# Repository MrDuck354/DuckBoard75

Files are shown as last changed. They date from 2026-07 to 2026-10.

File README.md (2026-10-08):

# DuckBoard 75

## Project Goals:
To create a basic 75% keyboard
By creating this keyboard, I will be learning how to 3D model/print on OnShape, how to create a PCB on KiCad and how to solder.

## Project Information
This project was inspired by a recent rabbit hole I went down in on youtube about custom keyboards, creators such as Glarses inspired me to get more into keyboards. Disappointed by my current HP office keyboard I wanted to get a mechanical keyboard but they're surprisingly expensive. I decided to design and build my own custom keyboard which would be a lot more affordable and a great learning opportunity for me. Also I just thought making my own keyboard would be a cool thing to flex on my friends...

The PCB was designed with the help of tutorials made by Joe Scotto on youtube, it doesn't feature anything cool, it's just a simple 75% keyboard PCB.
The case and top plate was made without any tutorials besides one to help me understand how OnShape works as I haven't used any of these softwares before. I want to make the case yellow or orange like a ducks bill so its more on theme for my name. 

My keyboard features 82 standard mechanical keys, its wired with an unpluggable wire but I could make it a permanent wire later on, I used a rp2042 because it seemed to be an option other people were suggesting on reddit, I chose Outemu switches because it was the cheapest option which was also reputable online and I decided on brown tactiles because they sound nice and tactile switches are probably closest to my current membrane keyboard but I don't know because I've never used a mechanical keyboard. I also thought about putting foam in between the bottom and the PCB which I may decided upon later once this project is approved and I get the parts (insert my decision here). There wasn't much thought behind my software choices, I chose OnShape because people online said it was good and I get it for free through my school and I chose KiCad because everyone said it was the best.

## Steps
Made a PCB on KiCad with an arduino nano RP2042 and switches, made the PCB first so that I can model the case around it. 


Made a top plate on OnShape using the PCB as a reference



Made a bottom case to fit everything and put it all together



Created the firmware using iNimbleSloth's tutorial on youtube https://www.youtube.com/watch?v=9bjp_LteX_Y
[Completed](duckboard_firmware)

Soldered the electronics together
(Not yet completed)

For more information on how I made these parts or how they fit together, check my [JOURNAL.md](JOURNAL.md) where I documented my design process.

## OnShape link
Click on the link below then copy and paste the link in a browser to go to OnShape

[OnShape Link](OnShapeLink.md)

Download the files in the link below if you want to edit or view them in another software
The assembly is too big to upload to GitHub so I had to compress it and can only add the .stl file and not the .step file. Unzip the .zip file and download the .stl file to view the case assembly.

[Case Files](DuckBoard_75_Case)

## Bill of Materials
[BOM.csv](DuckBoard%2075%20BOM%20-%20DuckBoard%2075%20BOM%20-%20Sheet1.csv)
| Item | Price (USD) | QTY | Purpose | Total + Shipping |
| --- | --- | --- | --- | --- |
| [PCB](https://cart.jlcpcb.com/quote?spm=jlcpcb.Public.2006) | $27.40 | 5 (minimum) | Electronics for keyboard |  |
| [Juidinto Hex Socket M2 Screws](https://www.aliexpress.com/item/1005004527586307.html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) | $2.33 | 1 | To hold everything together |  |
| [PBT Pudding Keycaps](https://www.aliexpress.com/item/1005012018517535.html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) | $20.65 | 1 | Keycaps |  |
| [DUROCK Plate Mount Stabilizers](https://www.aliexpress.com/item/1005006528731543.html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) | $8.84 | 1 | Stabilizers |  |
| [1N4148 Diodes](https://www.aliexpress.com/item/1005002339916163.html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) | $0.87 | 1 | to control flow of electricity |  |
| [Outemu Tactile Brown Switches](https://www.aliexpress.com/item/1005004285423123.html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) | $3.53 | 90pcs | switches |  |
| [RP2040 PICO Raspberry Pi Microcontroller](https://www.aliexpress.com/item/1005010706615847.html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) | $2.64 | 1 | to control everything |  |
| [Solder Wire](https://www.aliexpress.com/item/1005008618276811.html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) | $1.32 | 1 | to connect electronics |  |
| [3D printing costs](https://www.wcl.govt.nz/services/technology/makerspace/#costs)| $20 | 1 | to create the case| |
| AliExpress Shipping (No link to shipping costs) | $6.50 |  | To get the items |  |
| JLCPCB Shipping (No link to shipping costs) | $20.69 |  | To get the PCB |  |
| Total Cost |  |  |  | $113.89 |

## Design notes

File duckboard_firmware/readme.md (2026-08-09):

# duckboard_firmware

duckboard_firmware

*A short description of the keyboard/project*

* Keyboard Maintainer: [Shrimp](https://github.com/MrDuck354)
* Hardware Supported: *The PCBs, controllers supported*
* Hardware Availability: *Links to where you can find this hardware*

Make example for this keyboard (after setting up your build environment):

    make duckboard_firmware:default

Flashing example for this keyboard:

    make duckboard_firmware:default:flash

See the [build environment setup](https://docs.qmk.fm/#/getting_started_build_tools) and the [make instructions](https://docs.qmk.fm/#/getting_started_make_guide) for more information. Brand new to QMK? Start with our [Complete Newbs Guide](https://docs.qmk.fm/#/newbs).

## Bootloader

Enter the bootloader in 3 ways:

* **Bootmagic reset**: Hold down the key at (0,0) in the matrix (usually the top left key or Escape) and plug in the keyboard
* **Physical reset button**: Briefly press the button on the back of the PCB - some may have pads you must short instead
* **Keycode in layout**: Press the key mapped to `QK_BOOT` if it is available

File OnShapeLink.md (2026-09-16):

Adding the link to text in the readme wouldn't work for some reason so just copy and paste this link into your browser and it should open

WHEN IN THE ONSHAPE LINK, CLICK ON THE BOTTOM TO VIEW THE TOP PLATE, PCB AND CASE ASSEMBLY.

https://cad.onshape.com/documents/4c033f6297ba6398e5391c7b/w/0e4d4c66a045f8ad3cab1360/e/c171d3ecafdf5e42b058cd5b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

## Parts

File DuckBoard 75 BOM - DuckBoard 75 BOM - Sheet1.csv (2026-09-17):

Item | Link to site | Price (USD) | QTY | Purpose | Total + shipping
PCB | https://cart.jlcpcb.com/quote?spm=jlcpcb.Public.2006 | $27.40 | 5 (minimum) | Electronics for keyboard
Juidinto Hex Socket M2 Screws | https://www.aliexpress.com/item/1005004527586307.html?mp=1 | $2.33 | 1 | To hold everything together
PBT Pudding Keycaps | https://www.aliexpress.com/item/1005012018517535.html?curPageLogUid=qlyhQy7xRVpn | $20.65 | 1 | Keycaps
DUROCK Plate Mount Stabilizers | https://www.aliexpress.com/item/1005006528731543.html?mp=1 | $8.84 | 1 | Stabilizers
1N4148 Diodes | https://www.aliexpress.com/item/1005002339916163.html?curPageLogUid=11r81NCdmT7s | $0.87 | 1 | to control flow of electricity
Outemu Tactile Brown Switches | https://www.aliexpress.com/item/1005004285423123.html?curPageLogUid=kVSF8tEkUPWA | $3.53 | 90pcs | switches
RP2040 PICO Raspberry Pi Microcontroller | https://www.aliexpress.com/item/1005010706615847.html?mp=1&sourceType=570 | $1.76 | 1 | to control everything
solder wire | https://www.aliexpress.com/item/1005008618276811.html?mp=1&sourceType=570 | $1.32 | 1 | to connect electronics
3D print | https://www.wcl.govt.nz/services/technology/makerspace/#costs | $20.00 | 1 | to create the case
AliExpress Shipping | No link as cost is from all the parts | $6.50 |  | To get the items
JLCPCB Shipping | No link as cost is for shipping for the PCB | $20.69 |  | To get the PCB
Total cost |  |  |  |  | $113.89

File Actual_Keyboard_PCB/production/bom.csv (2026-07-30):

Designator | Footprint | Quantity | Value | LCSC Part #
A1 | Arduino_Nano | 1 | Arduino_Nano_RP2040_Connect
D1, D10, D11, D12, D13, D14, D15, D16, D17, D18, D19, D2, D20, D21, D22, D23, D24, D25, D26, D27, D28, D29, D3, D30, D31, D32, D33, D34, D35, D36, D37, D38, D39, D4, D40, D41, D42, D43, D44, D45, D46, D47, D48, D49, D5, D50, D51, D52, D53, D54, D55, D56, D57, D58, D59, D6, D60, D61, D62, D63, D64, D65, D66, D67, D68, D69, D7, D70, D71, D72, D73, D74, D75, D76, D77, D78, D79, D8, D80, D81, D82, D9 | Diode_DO-35 | 82 | ~
S1, S10, S11, S12, S13, S14, S15, S16, S17, S18, S19, S2, S20, S21, S22, S23, S24, S25, S26, S27, S29, S3, S31, S32, S33, S34, S35, S36, S37, S38, S39, S4, S40, S41, S42, S44, S46, S47, S48, S49, S5, S50, S51, S52, S53, S54, S55, S56, S58, S6, S60, S61, S62, S63, S64, S65, S66, S67, S68, S69, S7, S71, S8, S80, S81, S82, S9 | MX_PCB_1.00u | 67 | ~
S28 | MX_PCB_2.00u | 1 | ~
S30, S43 | MX_PCB_1.50u | 2 | ~
S45 | MX_PCB_1.75u | 1 | ~
S57, S59 | MX_PCB_2.25u | 2 | ~
S70 | MX_PCB_2.75u | 1 | ~
S72, S73, S74, S76, S77, S78, S79 | MX_PCB_1.25u | 7 | ~
S75 | MX_PCB_6.25u | 1 | ~
S83, S84 | STAB_MX_P_2.25u | 2 | MX_stab
S85 | STAB_MX_P_2.75u | 1 | MX_stab
S86 | STAB_MX_2u | 1 | MX_stab
S87 | STAB_MX_P_6.25u | 1 | MX_stab

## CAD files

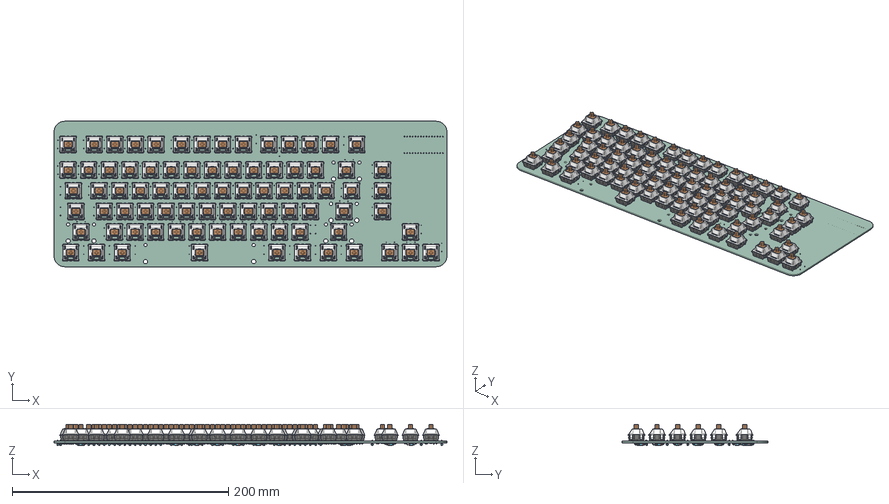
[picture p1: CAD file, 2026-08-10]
Actual_Keyboard_PCB/Actual_Keyboard_PCB.step
363.1 x 134.5 x 19.6 mm
SW_Cherry_MX_PCB_cp x 82
D_DO-35_SOD27_P7.62mm_Horizontal x 82
Act8265_PCB

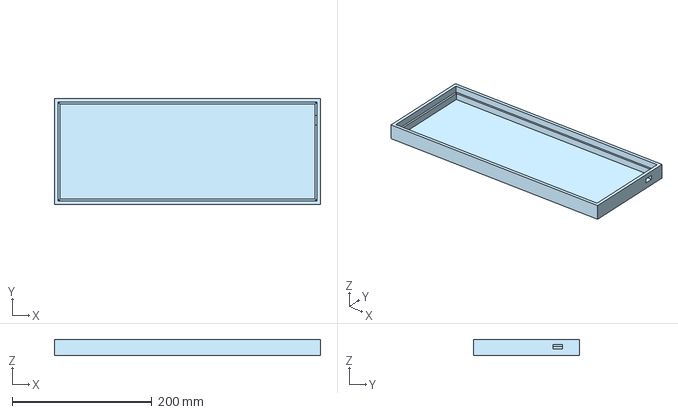
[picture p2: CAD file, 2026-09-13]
DuckBoard_75_Case/Bottom Case.step
381.0 x 152.0 x 23.0 mm

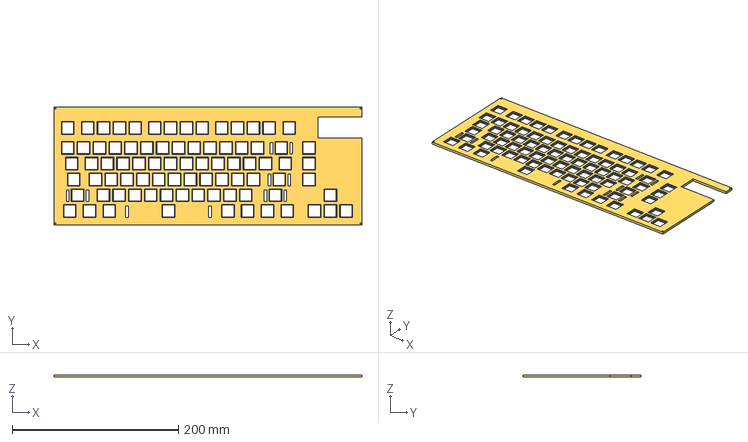
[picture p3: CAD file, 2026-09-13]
DuckBoard_75_Case/Keyboard Plate.step
371.0 x 142.0 x 3.00 mm

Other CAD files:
DuckBoard_75_Case/Bottom Case.stl
DuckBoard_75_Case/Keyboard Plate.stl

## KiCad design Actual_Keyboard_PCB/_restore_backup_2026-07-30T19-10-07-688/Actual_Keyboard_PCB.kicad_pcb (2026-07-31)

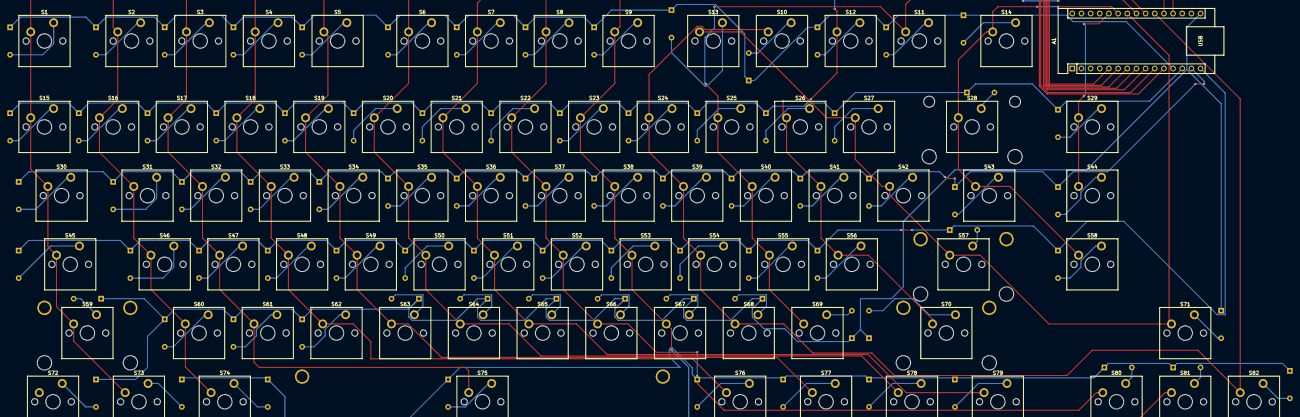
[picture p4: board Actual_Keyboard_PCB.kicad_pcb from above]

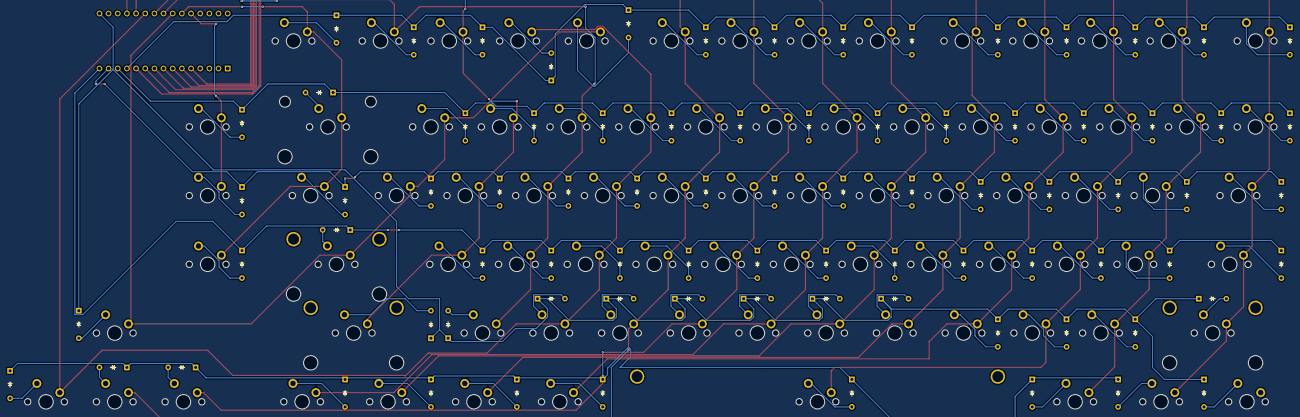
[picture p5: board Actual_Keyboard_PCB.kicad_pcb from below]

Board: 2 copper layers, 170 parts (82 on the bottom side), 104 nets.

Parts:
A1: Arduino_Nano_RP2040_Connect; Arduino_Nano
D1, D2, D3, D4, D5, D6, D7, D8, D9, D10, D11, D12, D13, D14, D15, D16, D17, D18, D19, D20, D21, D22, D23, D24, D25, D26, D27, D28, D29, D30, D31, D32, D33, D34, D35, D36, D37, D38, D39, D40, D41, D42, D43, D44, D45, D46, D47, D48, D49, D50, D51, D52, D53, D54, D55, D56, D57, D58, D59, D60, D61, D62, D63, D64, D65, D66, D67, D68, D69, D70, D71, D72, D73, D74, D75, D76, D77, D78, D79, D80, D81, D82: Diode_DO-35
S1, S2, S3, S4, S5, S6, S7, S8, S9, S10, S11, S12, S13, S14, S15, S16, S17, S18, S19, S20, S21, S22, S23, S24, S25, S26, S27, S29, S31, S32, S33, S34, S35, S36, S37, S38, S39, S40, S41, S42, S44, S46, S47, S48, S49, S50, S51, S52, S53, S54, S55, S56, S58, S60, S61, S62, S63, S64, S65, S66, S67, S68, S69, S71, S80, S81, S82: MX_PCB_1.00u
S28: MX_PCB_2.00u
S30, S43: MX_PCB_1.50u
S45: MX_PCB_1.75u
S57, S59: MX_PCB_2.25u
S70: MX_PCB_2.75u
S72, S73, S74, S76, S77, S78, S79: MX_PCB_1.25u
S75: MX_PCB_6.25u
S83, S84: MX_stab; STAB_MX_P_2.25u
S85: MX_stab; STAB_MX_P_2.75u
S86: MX_stab; STAB_MX_2u
S87: MX_stab; STAB_MX_P_6.25u

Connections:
/Column 0: A1.5 (D2), S1.1, S15.1, S30.1, S45.1, S59.1, S73.1
/Column 1: A1.6 (D3), S2.1, S16.1, S31.1, S46.1, S60.1, S74.1
/Column 2: A1.7 (D4), S3.1, S17.1, S32.1, S47.1, S61.1, S75.1
/Column 3: A1.8 (D5), S4.1, S18.1, S33.1, S48.1, S62.1, S76.1
/Column 4: A1.9 (D6), S5.1, S19.1, S34.1, S49.1, S63.1, S77.1
/Column 5: A1.10 (D7), S6.1, S20.1, S35.1, S50.1, S64.1, S78.1
/Column 6: A1.11 (D8), S7.1, S21.1, S36.1, S51.1, S65.1, S79.1
/Column 7: A1.19 (A0), S8.1, S22.1, S37.1, S52.1, S66.1, S80.1
/Column 8: A1.20 (A1), S9.1, S23.1, S38.1, S53.1, S67.1, S81.1
/Column 9: A1.21 (A2), S10.1, S24.1, S39.1, S54.1, S68.1, S82.1
/Column 10: A1.22 (A3), S11.1, S25.1, S40.1, S55.1, S69.1
/Column 11: A1.23 (SDA/A4), S12.1, S26.1, S41.1, S56.1, S70.1
/Column 12: A1.24 (SCL/A5), S13.1, S27.1, S42.1, S57.1, S71.1
/Column 13: A1.25 (A6), S14.1, S28.1, S43.1, S58.1, S72.1
/Column 14: A1.26 (A7), S29.1, S44.1
/Row 0: A1.12 (D9), D1.1 (K), D2.1 (K), D3.1 (K), D4.1 (K), D5.1 (K), D6.1 (K), D7.1 (K), D8.1 (K), D9.1 (K), D10.1 (K), D11.1 (K), D12.1 (K), D13.1 (K), D14.1 (K)
/Row 1: A1.13 (D10/CS), D15.1 (K), D16.1 (K), D17.1 (K), D18.1 (K), D19.1 (K), D20.1 (K), D21.1 (K), D22.1 (K), D23.1 (K), D24.1 (K), D25.1 (K), D26.1 (K), D27.1 (K), D28.1 (K), D29.1 (K)
/Row 2: A1.14 (D11/COPI), D30.1 (K), D31.1 (K), D32.1 (K), D33.1 (K), D34.1 (K), D35.1 (K), D36.1 (K), D37.1 (K), D38.1 (K), D39.1 (K), D40.1 (K), D41.1 (K), D42.1 (K), D43.1 (K), D44.1 (K)
/Row 3: A1.15 (D12/CIPO), D45.1 (K), D46.1 (K), D47.1 (K), D48.1 (K), D49.1 (K), D50.1 (K), D51.1 (K), D52.1 (K), D53.1 (K), D54.1 (K), D55.1 (K), D56.1 (K), D57.1 (K), D58.1 (K)
/Row 4: A1.16 (D13/SCK), D59.1 (K), D60.1 (K), D61.1 (K), D62.1 (K), D63.1 (K), D64.1 (K), D65.1 (K), D66.1 (K), D67.1 (K), D68.1 (K), D69.1 (K), D70.1 (K), D71.1 (K), D72.1 (K)
/Row 6: D73.1 (K), D74.1 (K), D75.1 (K), D76.1 (K), D77.1 (K), D78.1 (K), D79.1 (K), D80.1 (K), D81.1 (K), D82.1 (K)
unnamed: A1.4 (GND), A1.29 (GND)
unnamed: D1.2 (A), S1.2
unnamed: D2.2 (A), S2.2
unnamed: D3.2 (A), S3.2
unnamed: D4.2 (A), S4.2
unnamed: D5.2 (A), S5.2
unnamed: D6.2 (A), S6.2
unnamed: D7.2 (A), S7.2
unnamed: D8.2 (A), S8.2
unnamed: D9.2 (A), S9.2
unnamed: D10.2 (A), S10.2
unnamed: D11.2 (A), S11.2
unnamed: D12.2 (A), S12.2
unnamed: D13.2 (A), S13.2
unnamed: D14.2 (A), S14.2
unnamed: D15.2 (A), S15.2
unnamed: D16.2 (A), S16.2
unnamed: D17.2 (A), S17.2
unnamed: D18.2 (A), S18.2
unnamed: D19.2 (A), S19.2
unnamed: D20.2 (A), S20.2
unnamed: D21.2 (A), S21.2
unnamed: D22.2 (A), S22.2
unnamed: D23.2 (A), S23.2
unnamed: D24.2 (A), S24.2
unnamed: D25.2 (A), S25.2
unnamed: D26.2 (A), S26.2
unnamed: D27.2 (A), S27.2
unnamed: D28.2 (A), S28.2
unnamed: D29.2 (A), S29.2
unnamed: D30.2 (A), S30.2
unnamed: D31.2 (A), S31.2
unnamed: D32.2 (A), S32.2
unnamed: D33.2 (A), S33.2
unnamed: D34.2 (A), S34.2
unnamed: D35.2 (A), S35.2
unnamed: D36.2 (A), S36.2
unnamed: D37.2 (A), S37.2
unnamed: D38.2 (A), S38.2
unnamed: D39.2 (A), S39.2
unnamed: D40.2 (A), S40.2
unnamed: D41.2 (A), S41.2
unnamed: D42.2 (A), S42.2
unnamed: D43.2 (A), S43.2
unnamed: D44.2 (A), S44.2
unnamed: D45.2 (A), S45.2
unnamed: D46.2 (A), S46.2
unnamed: D47.2 (A), S47.2
unnamed: D48.2 (A), S48.2
unnamed: D49.2 (A), S49.2
unnamed: D50.2 (A), S50.2
unnamed: D51.2 (A), S51.2
unnamed: D52.2 (A), S52.2
unnamed: D53.2 (A), S53.2
unnamed: D54.2 (A), S54.2
unnamed: D55.2 (A), S55.2
unnamed: D56.2 (A), S56.2
unnamed: D57.2 (A), S57.2
unnamed: D58.2 (A), S58.2
unnamed: D59.2 (A), S59.2
unnamed: D60.2 (A), S60.2
unnamed: D61.2 (A), S61.2
unnamed: D62.2 (A), S62.2
unnamed: D63.2 (A), S63.2
unnamed: D64.2 (A), S64.2
unnamed: D65.2 (A), S65.2
unnamed: D66.2 (A), S66.2
unnamed: D67.2 (A), S67.2
unnamed: D68.2 (A), S68.2
unnamed: D69.2 (A), S69.2
unnamed: D70.2 (A), S70.2
unnamed: D71.2 (A), S71.2
unnamed: D72.2 (A), S72.2
unnamed: D73.2 (A), S73.2
unnamed: D74.2 (A), S74.2
unnamed: D75.2 (A), S75.2
unnamed: D76.2 (A), S76.2
unnamed: D77.2 (A), S77.2
unnamed: D78.2 (A), S78.2
unnamed: D79.2 (A), S79.2
unnamed: D80.2 (A), S80.2
unnamed: D81.2 (A), S81.2
unnamed: D82.2 (A), S82.2

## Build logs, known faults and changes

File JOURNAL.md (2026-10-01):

---
title: "DuckBoard75"
author: "MrDuck354"
description: "A basic 75% keyboard with a 3d printed case, plate and a custom PCB"
created_at: "2026-07-23"
---

# July 29th: Designing my own PCB

Since the most expensive part of my keyboard is the PCB, I decided to just create my own on KiCad which would be a more cost effective option. Although I would have to redesign my case but that's fine. First I watched a tutorial online by Joe Scotto which helped me learn how to use KiCad and what a keyboard matrix is and how it works. Following his tutorial, I designed a 3x3 grid PCB, switches and all, these skills that I learned from Joe Scotto directly helped me build a keyboard PCB. This is a photo of that PCB that I built from his tutorial



After that, I went ahead and started designing my own PCB with a 75% keyboard layout. This was very similar to the tutorial except I chose my own micro controller which would be the RP2040 since it's cheap and other people who did a similar project to me recommended it online and I also added stabilizers for my longer keys.




Next steps: I will align all the parts of the PCB to make it look like an actual keyboard, then I'll redesign the case around this new PCB.

**Total time spent: 2.3 hours**

# July 30th: Finishing PCB and starting the case

Started by putting labels on all the connections I need so that I can see what isn't connected yet in the PCB tool. I then put all the switches in the correct spots and wired them up, then I added the diodes and wired them together. This whole process was very time consuming, I also went back to Scotto's tutorial to check if I missed anything or not. I added my PCB files to Github. Here's photos of my finished PCB





I then added my PCB into onshape to design my case around this new PCB. I decided to just completely redesign the case and start from scratch which I thought would be easier, I also decided on making a bottom mount case. I started with designing the plate on the PCB but my laptop was really struggling with this and it became really slow to use the software, I got a bit frustrated by this so I decided to just leave it for tomorrow. Here's my timelapse: https://lapse.hackclub.com/timelapse/ggHCVTWVpvnO
Next steps: Continue designing the plate and then the case.

**Total time spent: 2.6 hours**

# July 31st: Finishing the plate

Started off by adding squares in the plate for the switches to go into. They're supposed to be 14mm because that's the size holes that standard MX switches clip into but I made them 14.15mm because of any plastic shrinkage that may happen when I 3D print the case. After that I did a bit more research on the case and I wanted to add a line art of a duck to the case to make it more personalized but I had no clue how to re size a .dxf file so i'm just gonna leave that to a later date. The plate is 3mm thick but it needs to be 1.5mm around the switch for it to properly clip in so I added a second square which was extruded to 1.5mm instead of 3mm, I made the plate 3mm thick so that it wouldn't break easily under pressure. Here's some photos of the completed plate, i'll add screw holes later when I finish the bottom case because I don't really know where to put the holes right now.




Here's my timelapse: https://lapse.hackclub.com/timelapse/d68X6dKh54Kl
Next steps: Start the bottom and top parts of the case.

**Total time spent: 3.6 hours**

# August 1st: Finishing Case + BOM

Started off by creating the bottom case, I first measured the plate then made the inside of the case slightly larger so that the plate would fit. I then created the walls and put the plate in to see if it would all fit. I then added screw holes to the case and the plate. I did a bit of research and it seems like most 3d printed cases don't use a top case and instead use the plate as the top so that's what I will do. I then realized that I never created a hole in the plate for the microcontroller to sit in so I added that. Here are some photos of the completed case and plate.




I then added the files to Github and began working on my BOM. For my BOM, all the parts are from aliexpress and 3 are apart of one of their bundle deals. I will fund the 3D printing myself






Heres my timelapse: https://lapse.hackclub.com/timelapse/eOVi5fF8ssbe
Next Steps: Create the firmware to put on the Microcontroller and get funding

**Total time spent: 2.3 hours**

# August 7th: Updated the README on Github

Updated the read me to include the BOM and changed the formatting to make it more organized by adding the onshape link, adding the steps I took and shortening the project goals




**Total time spent: 0.4 hours**

# August 9th: Fixing Onshape link and starting firmware

started off by fixing the OnShape link, instead of copying the url while I was working on it I had to click on the share button and use that url. I started looking around for tutorials and I settled on iNimbleSloth's tutorial https://www.youtube.com/watch?v=9bjp_LteX_Y



I watched through it once to make sure that it will actually be useful for me and it was. Next I will begin working through his tutorial though it seems like a lengthy process

**Total time spent: 0.8 hours**

# August 9th: Progressing through the firmware

I started working through the previously mentioned tutorial and got all the way through it up until I had to compile it.




When I tried to compile the code I got some errors and ended up spending so much time trying to fix it that I got frustrated and rage quit so I'll leave it till tomorrow or later today.



**Total time spent: 2.5 hours**

# August 9th: Completed firmware and fixed PCB

2 and a half hours of pain fixed in just over an hour... In the error found in the previous journal entry, it was because I had named the layout as "duckboard75" but qmk wants it in a certain format starting with LAYOUT so I changed it to "LAYOUT_75_ANSI" but that still gave an error because it's supposed to be "LAYOUT_75_ansi" so I fixed all that. Now I thought that that would be the end of the errors but I thought wrong. Once I tried compiling it again, I got a long list of warnings and errors (Shown below)




According to the errors, row 5 was never connected to the micro controller which I thought was an error I would never had made but low and behold I did in fact make that mistake. Row 5 was never connected to the micro controller so I remedied it by connecting row 5 to the D1 (GP1) pin and then adding that to the row thing in my code.





After that I encountered my second to last error which was my code had some keys connected to columns 15 and 16 but I only have columns 0-14. This was caused by my bottom row of keys jumping from 6 to 15 and I don't remember doing that but I guess I'm a bit dim. Once fixing that my last error was just having a semi colon in the wrong spot. I compiled the code successfully and uploaded the firmware and the fixed PCB to github. I also put the files into JLCPCB to see if it would cost more but it still costs the same amount.

**Total time spent: 1.2 hours**

# August 10th: Fixing the PCB

I did a bit of work at school during lunch. I made the corners of the PCB curved so it's not pointy but to move the micro controller to the edge of the PCB I need to re do a lot of the wiring so I just left it till I get home.



**Total time spent: 0.3 hours**

# August 10th: Fixing PCB pt 2 + fixing case/plate

Started off by adding the wires I left from last journal entry, not much to say about that.



Then I started on my plate where I moved the micro controller cut out to the edge to fit the new placement, then I added it to my assembly to see how it fit with my bottom case. When I put my plate in the proper place it turns out that it was a few mm off the screw holes so I increased the size of the plate and moved the switch holes to the right spots





After that I checked the fit with the PCB but when I hid the plate the PCB was slightly off center which meant that the switch holes in the plate were in the wrong spot so I fixed that easily.



Then I realized that I never added a hole for the wire to connect to the micro controller through the case so I spent a bit of time adding that.




Now everything is in the right places and fit together properly. Here are some screen shots of the finished product, I also added the plate and case files to GitHub but the assembly.stl file couldn't be added as it's too big due to the amount of parts the PCB has in OnShape so to see that you have to go to the OnShape link in my GitHub repo.




**Total time spent: 3 hours**

# August 19th: Changing BOM

I decided that It would be best for me to just get the funds for the 3d printed case through here, a library close to me has a makerspace with 3d printers, laser cutters etc and they charge 10 cents per gram of filament. I put my bottom case and plate through PrusaSlicer so I can see how much filament it would use. Since the 3D printer bed that the library has is 900x600mm, my parts fit on the bed without having to slice them in half, Prusa Slicer says that my bottom case and plate will use about 336 grams of filament and at 10 cents per gram, that's about $34 NZD which is about $20 USD at the current exchange rate. I then put this into all my BOM's and costs.




**Total time spent: 0.5 hours**

# September 18th: Fixing BOM

I added the proper names for both BOMs (the read me one and the .csv one) and fixed some of the links because they brought you to the shopping cart instead of the actual products. The keycaps were unavailable so I had to change them with different ones, these new keycaps were on sale for very cheap but the sale ends on the 21st of september so I put the normal price instead. This does raise the total price to $113.



**Total time spent: 0.5 hours**

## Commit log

2026-07-25 added a bill of materials and the cad file for my case
    [BOM for custom keyboard - Sheet1.csv, Keyboard Case.stl]
2026-07-30 Added PCB files
    [bom.csv, designators.csv, positions.csv]
2026-07-30 Delete BOM for custom keyboard - Sheet1.csv
    deleted old BOM
    [BOM for custom keyboard - Sheet1.csv]
2026-07-30 Delete Keyboard Case.step
    deleted old case files
    [Keyboard Case.step]
2026-07-30 Delete Keyboard Case.stl
    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
    [Keyboard Case.stl]
2026-07-31 Added Case files
    [Bottom Case.step, Bottom Case.stl, Keyboard Plate.step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]
2026-07-31 Add Onshape link for DuckBoard 75 Case
2026-08-01 Uploaded BOM
    [DuckBoard 75 BOM - Sheet1.csv]
2026-08-07 Update README with project goals and steps
    Expanded project goals and added detailed steps for creating a custom keyboard, including PCB design, 3D modeling, and soldering. Included links to OnShape and a Bill of Materials with pricing.
2026-08-07 Fix link formatting for BOM.csv in README
2026-08-07 Rename Actual_Keyboard_PCB.zip to DuckBoard 75 PCB Gerbers.zip
2026-08-09 Added firmware and fixed pcb
    [Actual_Keyboard_PCB.kicad_pcb, Actual_Keyboard_PCB.kicad_sch, Actual_Keyboard_PCB.step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]
2026-08-09 deleted old pcb files
    [Actual_Keyboard_PCB.kicad_pcb, Actual_Keyboard_PCB.kicad_sch, Actual_Keyboard_PCB.step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]
2026-08-10 added the new pcb files
    [Actual_Keyboard_PCB.kicad_pcb, Actual_Keyboard_PCB.kicad_sch, Actual_Keyboard_PCB.step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]
2026-08-10 Update README with new images and project status
    Added new images and updated the status of the firmware and electronics assembly.
2026-08-18 added 3D printing costs to BOM
2026-09-12 Add journal entries for keyboard project progress
    Documented the progress of designing and building a custom 75% keyboard, including PCB design, case creation, firmware development, and BOM updates.
2026-09-13 Added .STEP versions of the case files
    [Bottom Case.step, Keyboard Plate.step]
2026-09-13 Added .STEP versions of the case files and put them in the right place
    [Bottom Case.step, Keyboard Plate.step]
2026-09-16 Update DuckBoard 75 BOM - DuckBoard 75 BOM - Sheet1.csv
    [DuckBoard 75 BOM - DuckBoard 75 BOM - Sheet1.csv]
2026-09-16 Update BOM with new item details and links
    [DuckBoard 75 BOM - DuckBoard 75 BOM - Sheet1.csv]
2026-09-16 Enhance README with project details and links
    Updated README with detailed descriptions of the PCB, top plate, bottom case, firmware creation, and added a link to the design journal.
2026-09-16 Fix links in Bill of Materials section
2026-09-16 Update README with OnShape link and BOM details
    Added instructions for accessing OnShape and downloading case files.
2026-09-16 rename folder
    [Bottom Case.step, Bottom Case.stl, Keyboard Plate.step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]
2026-09-16 Update OnShapeLink with access instructions
    Added instructions for accessing the OnShape link and viewing the assembly.
2026-09-17 Revise BOM with updated prices and links
    Updated the Bill of Materials (BOM) with new item costs and links.
    [DuckBoard 75 BOM - DuckBoard 75 BOM - Sheet1.csv]
2026-09-17 Revise BOM with new items and total cost
    Updated item list and prices in the BOM section of the README.
2026-09-17 Fix BOM names and update keycap pricing in journal
    Updated journal entry for September 18th with corrections to BOM names, fixed links, and updated keycap pricing.
2026-10-01 Revise journal entry details and pricing
    Updated journal entry with proper BOM names, fixed links, and adjusted total price due to keycap changes.
2026-10-01 Revise journal entry for July 31st
    Updated journal entry to reflect progress on the plate design and adjustments made for switch holes.
2026-10-01 Fix date formatting and update PCB assembly notes
    Corrected formatting of the date header and added details about the PCB assembly process.
2026-10-31 Update JOURNAL.md with project progress details
    Documented project progress and challenges faced in splitting the plate for 3D printing, including design adjustments and techniques used.
2026-10-31 Update JOURNAL.md with progress on bottom case
    Documented progress on splitting the bottom case and total time spent.
2026-11-04 Revise JOURNAL.md with new entries and updates
    Updated journal entries with time spent and links to timelapses. Added details about fixing the plate and measurements for stabilizers.
